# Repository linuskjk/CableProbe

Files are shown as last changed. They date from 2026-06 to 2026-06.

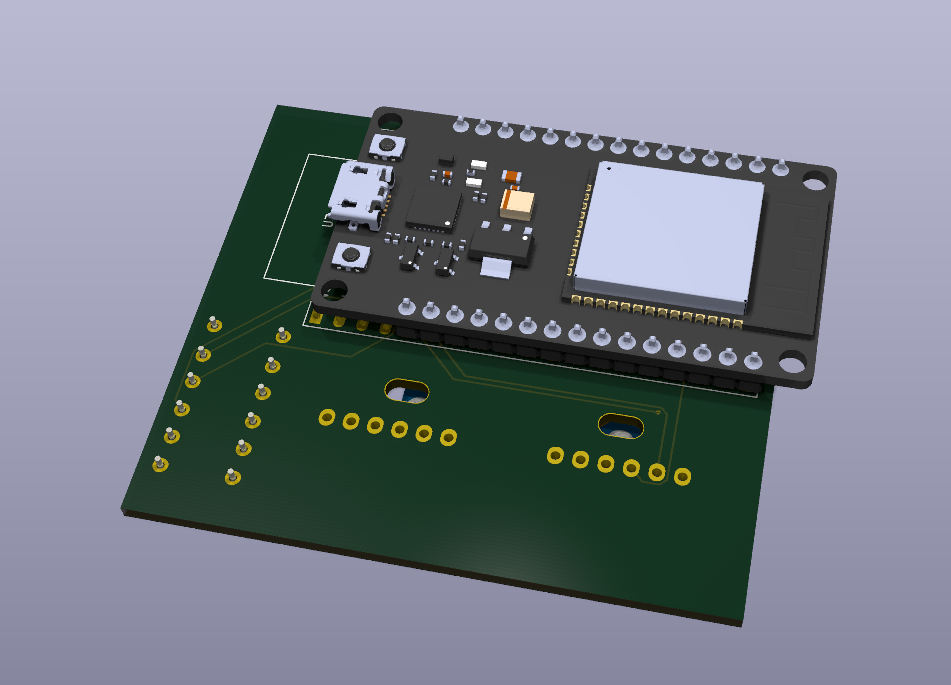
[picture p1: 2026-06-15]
images/pcb_bottom.png

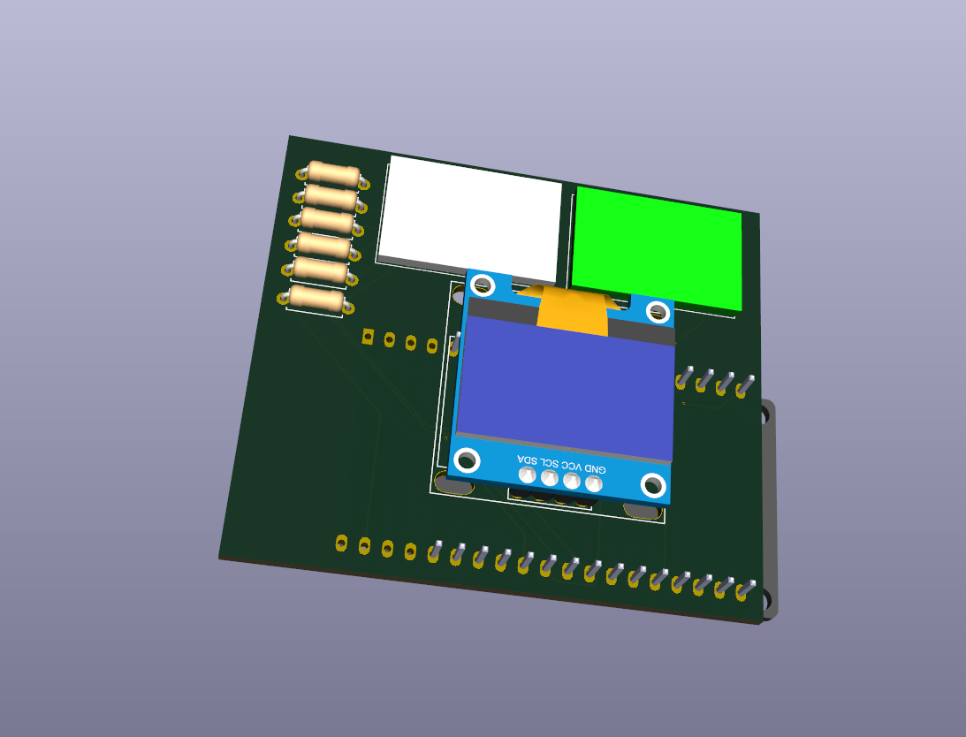
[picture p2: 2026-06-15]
images/pcb_top.png

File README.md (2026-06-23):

zine_page

# CableProbe

A custom ESP32-based tool to analyze and verify USB-C cables.

## TO THE REVIEWER PLEASE READ THE MESSAGE AT THE BOTTOM ;)
## Features

### Analysis
- Basic connectivity check
- Problem detection
- Power throughput & quality
- Fast Charging / Power Delivery support
- General-purpose suitability testing

## Hardware

- ESP32 on a custom PCB
- 2x USB-C modules linked to GPIOs
- 128x64 SSD1306 OLED display
- Basic resistor setup for pin pulling

## Why?

Ever bought a pile of cheap USB-C cables from AliExpress only to find out they are bad? Or struggled to figure out which cable actually supports fast charging?

CableProbe was made to quickly sort through the cable drawer. It identifies the quality and features of almost any USB-C cable without needing a PC or complicated setup.

## Usage

Simply plug both ends of your cable into the USB-C modules and follow the instructions on the screen.

The ESP32 will run through the pins and display the results on the screen. It immediately tells you whether the cable is suitable for:
- charging only,
- fast charging,
- or high-speed applications.

## Images

### Case



### PCB



### ROUTING
routing

### SCHEMATIC



### CASE
## IMPORTANT: THIS IS NOT THE NEWEST VERSION OF THE CASE BUT IT USES THE EXACT SAME FRICTION FIT SO IT ALSO WORKS ON THE NEW VERSION.

https://github.com/user-attachments/assets/e5118ca8-60bc-48c1-94f0-9f646d53b27a

### PROOF THAT MY FRICTION FIT WORKS

https://github.com/user-attachments/assets/f6ddad3f-a20b-4f4a-b254-9df56e5059d4

# Build Your Own

## PCB and Parts

| Reference | Qty | Value | Description | Price EUR | Pack Info | Link |
| --- | --: | --- | --- | ---: | --- | --- |
| Brd1 | 1 | 128x64 OLED | SSD1306 | 2.89 | 1 pc | [Buy](https://de.aliexpress.com/item/1005006514489341.html) |
| R1 R2 R3 R4 R5 R6 | 6 | 1k Ohm | R_Axial_DIN0207_L6.3mm_D2.5mm_P7.62mm_Horizontal | 3.30 | 20 pcs | [Buy](https://amzn.eu/d/0aSOhZVj) |
| U1 U2 | 2 | USB-C Module  | USB-C connector module to connect the cable to | 1.61 | 5 pcs | [Buy](https://de.aliexpress.com/item/1005007314733520.html) |
| U3 | 1 | ESP32-DevKitC | ESP32 development board | 2.99 | 1 pc | [Buy](https://de.aliexpress.com/item/1005006140555903.html) |
| Battery | 1 | 654060 Li-Po 200mAh | Lithium polymer battery | 9.90 | 1 pc | [Buy](https://de.aliexpress.com/item/1005005970679252.html) |
| Charger Module | 1 | TP4057 | USB-C charging module | 3.83 | 1 pc | [Buy](https://de.aliexpress.com/item/1005010764961491.html) |

The PCB is a simple custom design made to hold the ESP32, USB-C modules, and OLED display in a compact enclosure.

## Soldering 

Recommended order:
1. Resistors
2. ESP32
3. USB-C modules
4. OLED display

No special equipment needed.

## Case

3D print the provided STL files.

Both PLA and PETG work perfectly fine. I recommend using PLA. 
I have already printed and tested the case. The friction fit works perfectly, and the battery mount fits exactly as intended. The PCB and firmware have also been tested and are working correctly.

## Programming 

**Install the following libraries** (you can find them under firmware/libraries or the library manager:
- *Adafruit_GFX.h*
- *Adafruit_SSD1306.h*

**Flashing** is straightforward:
1. Open 'main.ino' from the 'firmware' folder in your preferred IDE.
2. Select the correct ESP32 board (ESP32 DevKit).
3. Hit upload

## Assembly 

1. Drop the PCB into the bottom half of the case
2. Connect the battery to the charger module (B+/- to the battery terminals and the module output to V+/GND). The charger module is intentionally not mounted on the PCB to save space and allow more flexible battery placement. Simply press the module into the slot at the bottom of the case. It fits securely and withstands considerable force.
3. Align the USB-C ports with the openings
4. Fit the OLED display into place
5. Close the enclosure

To the reviewer: I cant resubmit this anymore so if you reject it I have some serious problems. I already booked my flights and bought a laptop just for the event. I am going homeless if I cant go. But IF there is a problem with my project, can you just not reject it but tell me what to do and after it is done you can approve it. PLEASE. and also if you are wondering about the 3D models of the USB-C modules on the PCB, I unfortunately couldn't find any suitable 3D models for them and was advised to leave them as they are.

Everything is designed to fit snugly without additional hardware.

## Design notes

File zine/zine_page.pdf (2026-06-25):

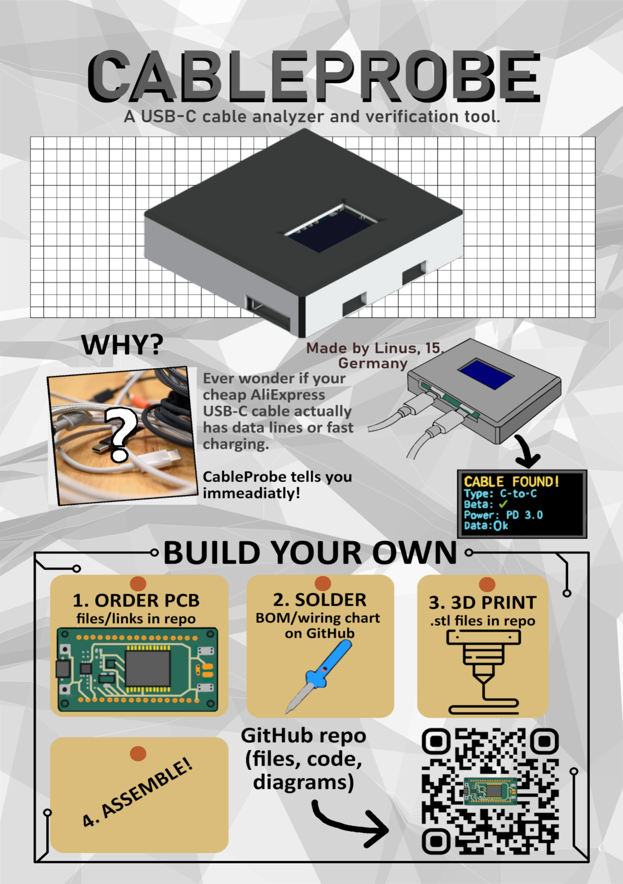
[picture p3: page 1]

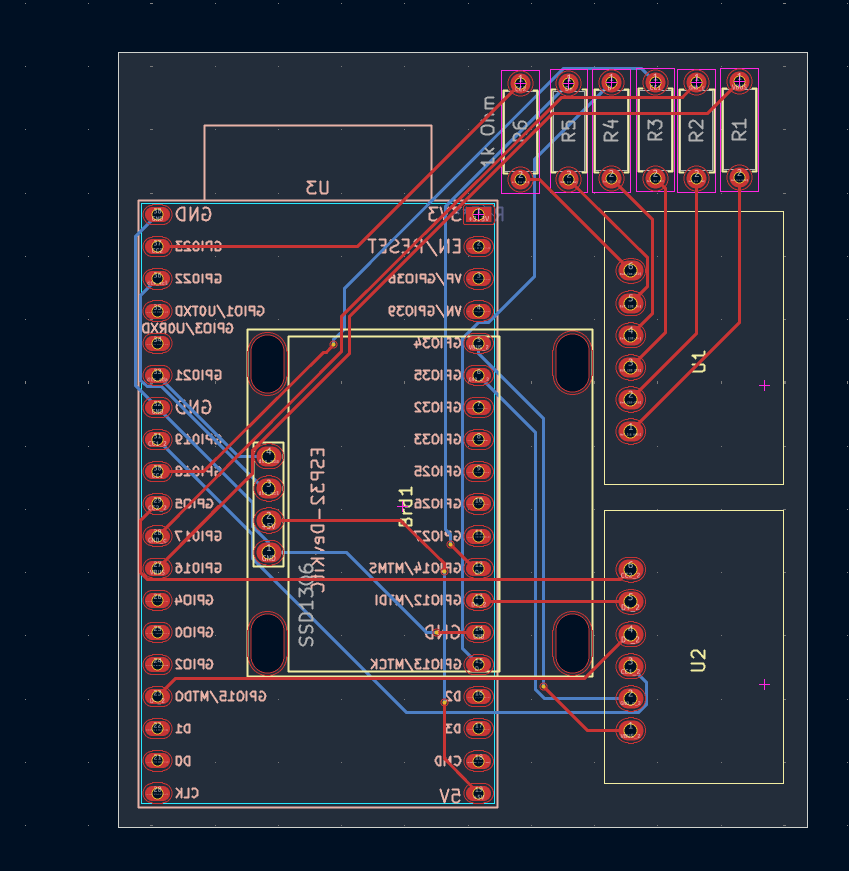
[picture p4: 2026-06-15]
images/routing.png

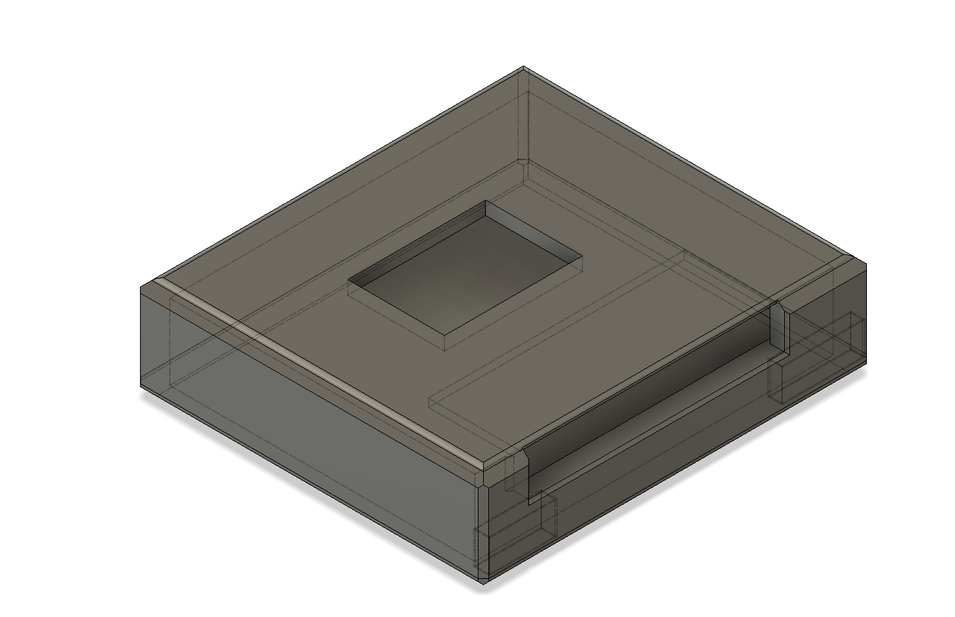
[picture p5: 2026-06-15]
images/case.png

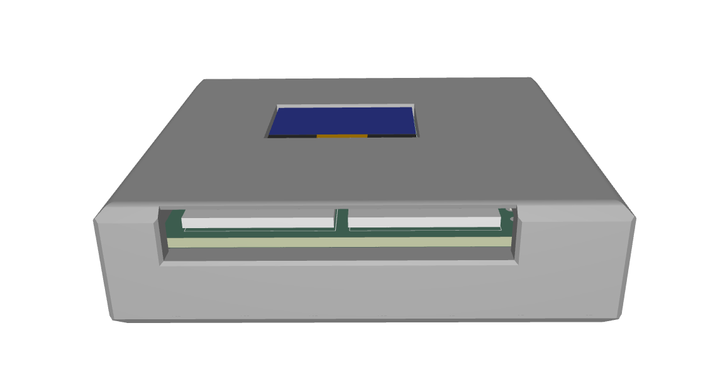
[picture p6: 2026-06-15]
images/case2.png

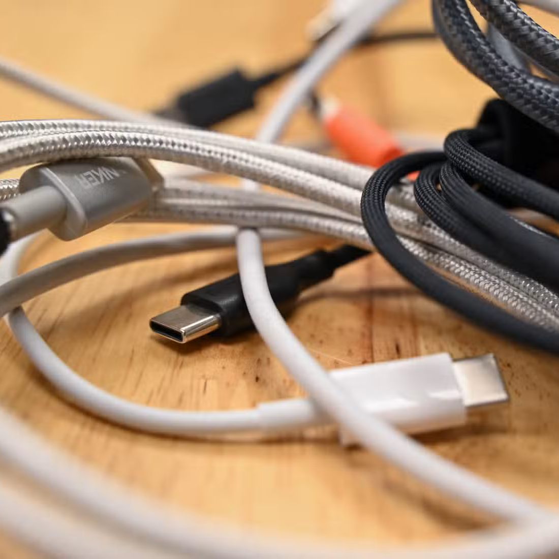
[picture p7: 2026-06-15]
zine/cables.png

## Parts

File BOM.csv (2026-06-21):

Reference | Qty | Value | Description | Price EUR | Pack Info | Link
Brd1 | 1 | 128x64OLED | SSD1306 | 2.89 | 1 pcs | https://de.aliexpress.com/item/1005006514489341.html
R1, R2, R3, R4, R5, R6 | 6 | 1k Ohm | R_Axial_DIN0207_L6.3mm_D2.5mm_P7.62mm_Horizontal | 3.30 | 20 pcs | https://amzn.eu/d/0aSOhZVj
U1, U2 | 2 | usbc_module | usb-c connector module to connect the cable to | 1.61 | 5 | https://de.aliexpress.com/item/1005007314733520.html
U3 | 1 | ESP32-DevKitC | ESP32 development board | 2.99 | 1 pc | https://de.aliexpress.com/item/1005006140555903.html
BAT1 | 1 | 654060 Li-Po 200mAh | Lithium polymer battery | 9.90 | 1 pc | https://de.aliexpress.com/item/1005005970679252.html
U4 | 1 | TP4057 | USB-C charging module | 3.83 | 1 pc | https://de.aliexpress.com/item/1005010764961491.html
TOTAL |  |  | Total price | 24.52 / 21.24

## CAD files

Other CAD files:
case/fully_assembled.step
pcb/pcb_model_not_assembled.step
pcb/pcb_model_assembled.step
case/case.step
case/case.3mf
case/case.f3z
case/case.obj
case/case.stl
case/fully_assembled.3mf
case/fully_assembled.f3z
case/fully_assembled.obj
case/fully_assembled.stl
pcb/pcb_model_assembled.stl
pcb/pcb_model_not_assembled.stl

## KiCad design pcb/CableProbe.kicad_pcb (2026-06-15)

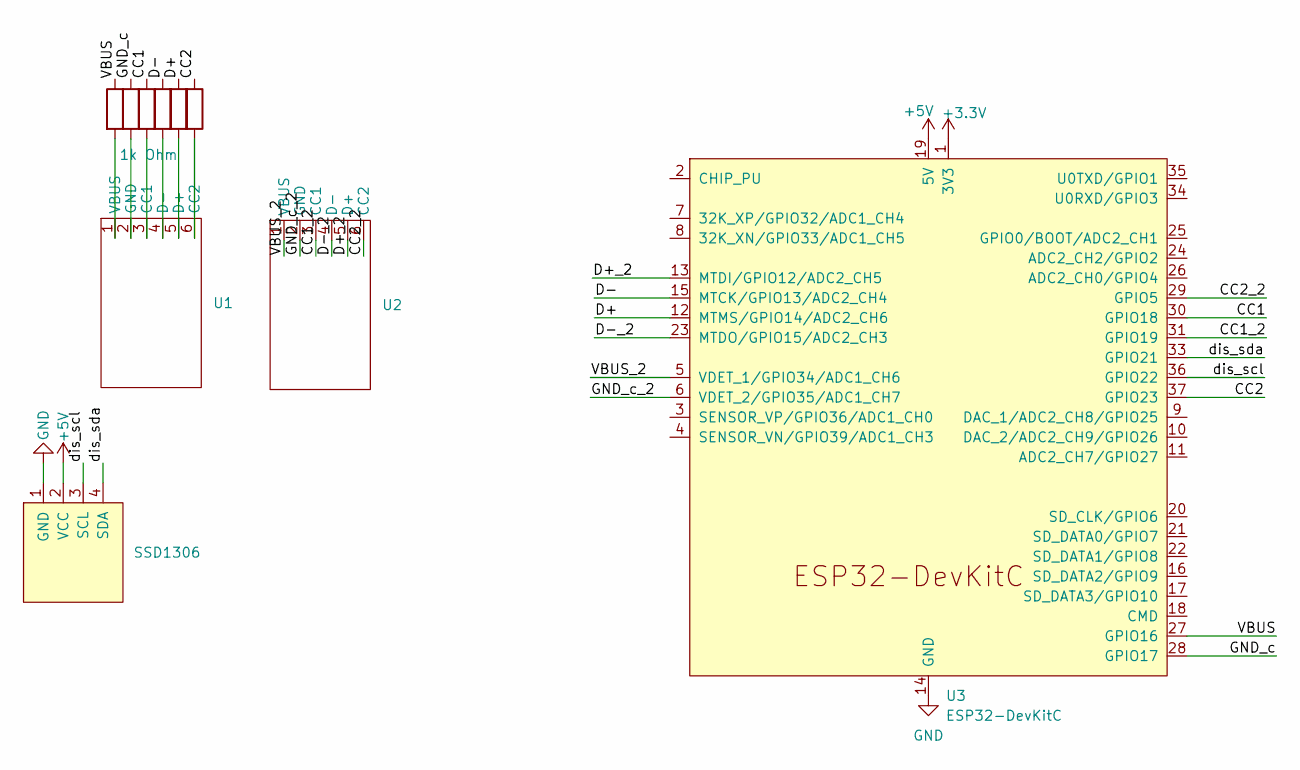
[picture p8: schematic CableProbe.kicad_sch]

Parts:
Brd1: SSD1306; 128x64OLED
R1, R2, R3, R4, R5, R6: 1k Ohm; R_Axial_DIN0207_L6.3mm_D2.5mm_P7.62mm_Horizontal
U1, U2: usbc_bb
U3: ESP32-DevKitC

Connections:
+3.3V: U3.1 (3V3)
+5V: Brd1.2 (VCC), U3.19 (5V)
/CC1: R3.1, U3.30 (GPIO18)
/CC1_2: U2.3 (CC1), U3.31 (GPIO19)
/CC2: R6.1, U3.37 (GPIO23)
/CC2_2: U2.6 (CC2), U3.29 (GPIO5)
/D+: R5.1, U3.12 (MTMS/GPIO14/ADC2_CH6)
/D+_2: U2.5 (D+), U3.13 (MTDI/GPIO12/ADC2_CH5)
/D-: R4.1, U3.15 (MTCK/GPIO13/ADC2_CH4)
/D-_2: U2.4 (D-), U3.23 (MTDO/GPIO15/ADC2_CH3)
/GND_c: R2.1, U3.28 (GPIO17)
/GND_c_2: U2.2 (GND), U3.6 (VDET_2/GPIO35/ADC1_CH7)
/VBUS: R1.1, U3.27 (GPIO16)
/VBUS_2: U2.1 (VBUS), U3.5 (VDET_1/GPIO34/ADC1_CH6)
/dis_scl: Brd1.3 (SCL), U3.36 (GPIO22)
/dis_sda: Brd1.4 (SDA), U3.33 (GPIO21)
GND: Brd1.1 (GND), U3.14 (GND), U3.32 (GND), U3.38 (GND)
unnamed: R3.2, U1.3 (CC1)
unnamed: R6.2, U1.6 (CC2)
unnamed: R5.2, U1.5 (D+)
unnamed: R4.2, U1.4 (D-)
unnamed: R2.2, U1.2 (GND)
unnamed: R1.2, U1.1 (VBUS)

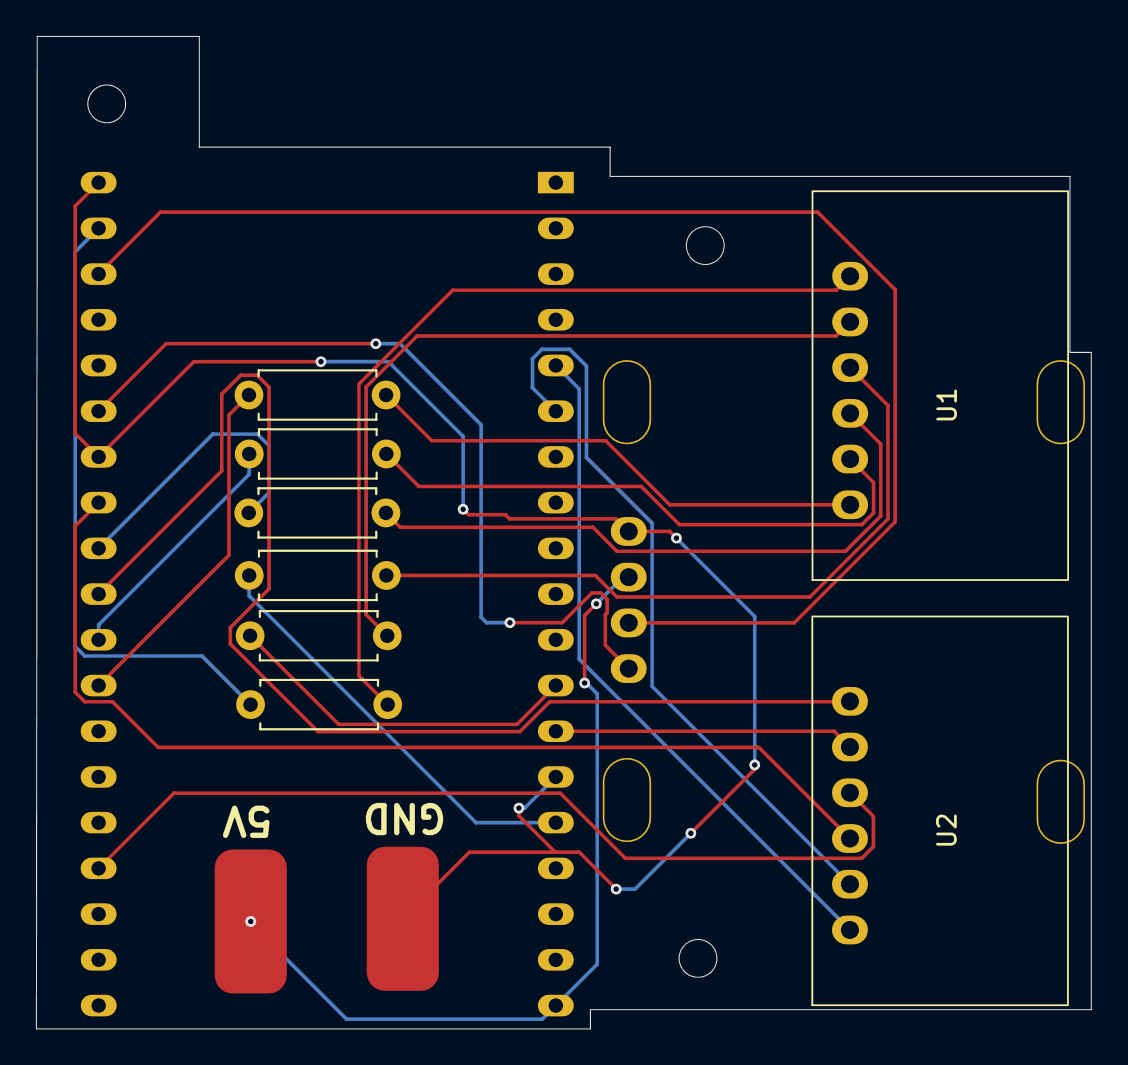
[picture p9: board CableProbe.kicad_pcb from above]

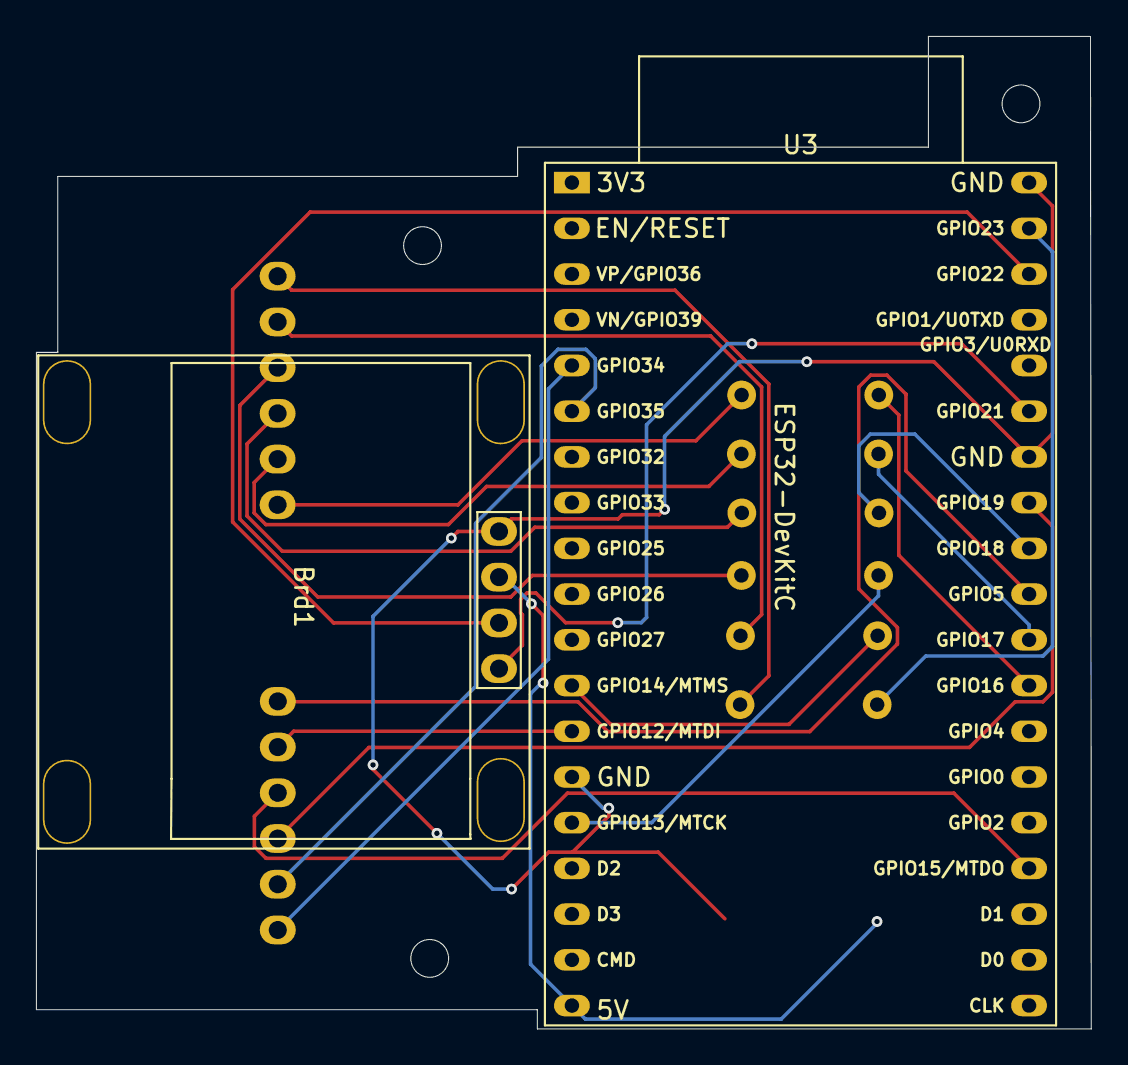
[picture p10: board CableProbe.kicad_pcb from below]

Board: 2 copper layers, 58.6 x 55.1 mm, 13 parts (2 on the bottom side), 22 nets.

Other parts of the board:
M1, M2, M3: MountingHole_2.1mm

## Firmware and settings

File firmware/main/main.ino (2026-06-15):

#include <SPI.h>
#include <Wire.h>
#include <Adafruit_GFX.h>
#include <Adafruit_SSD1306.h>

#define SCREEN_WIDTH 128
#define SCREEN_HEIGHT 64

#define OLED_RESET    -1 
Adafruit_SSD1306 display(SCREEN_WIDTH, SCREEN_HEIGHT, &Wire, OLED_RESET);



#define VBUS_OUT    13
#define GND_OUT     12
#define CC1_OUT     14
#define D_minus_OUT 27
#define D_plus_OUT  26
#define CC2_OUT     25

#define VBUS_IN     33
#define GND_IN      32
#define CC1_IN      19
#define D_minus_IN  18
#define D_plus_IN   4   
#define CC2_IN      5   


static const unsigned char PROGMEM logo_bmp[] = { 
	0x00, 0x00, 0x00, 0x00, 0x00, 0x00, 0x00, 0x00, 0x00, 0x00, 0x00, 0x00, 0x00, 0x00, 0x00, 0x00, 
	0x00, 0x00, 0x00, 0x00, 0x00, 0x00, 0x00, 0x00, 0x00, 0x00, 0x00, 0x00, 0x00, 0x00, 0x00, 0x00, 
	0x00, 0x00, 0x00, 0x00, 0x00, 0x00, 0x00, 0x00, 0x00, 0x00, 0x00, 0x00, 0x00, 0x00, 0x00, 0x00, 
	0x00, 0x00, 0x00, 0x00, 0x00, 0x00, 0x00, 0x00, 0x00, 0x00, 0x00, 0x00, 0x00, 0x00, 0x00, 0x00, 
	0x00, 0x00, 0x00, 0x00, 0x00, 0x00, 0x00, 0x00, 0x00, 0x00, 0x00, 0x00, 0x00, 0x00, 0x00, 0x00, 
	0x00, 0x00, 0x00, 0x00, 0x00, 0x00, 0x00, 0x00, 0x00, 0x00, 0x00, 0x00, 0x00, 0x00, 0x00, 0x00, 
	0x00, 0x00, 0x00, 0x00, 0x00, 0x00, 0x00, 0x00, 0x00, 0x00, 0x00, 0x00, 0x00, 0x00, 0x00, 0x00, 
	0x00, 0x00, 0x00, 0x00, 0x00, 0x00, 0x00, 0x00, 0x00, 0x00, 0x00, 0x00, 0x00, 0x00, 0x00, 0x00, 
	0x00, 0x00, 0x00, 0x00, 0x00, 0x00, 0x00, 0x00, 0x00, 0x00, 0x00, 0x00, 0x00, 0x00, 0x00, 0x00, 
	0x00, 0x00, 0x00, 0x00, 0x00, 0x00, 0x00, 0x00, 0x00, 0x00, 0x00, 0x00, 0x00, 0x00, 0x00, 0x00, 
	0x00, 0x00, 0x7f, 0xff, 0xff, 0xfe, 0x00, 0x00, 0x00, 0x03, 0xff, 0xff, 0xff, 0xff, 0xc0, 0x00, 
	0x00, 0x07, 0xff, 0xff, 0xff, 0xff, 0xe0, 0x00, 0x00, 0x0f, 0xff, 0xff, 0xff, 0xff, 0xf8, 0x00, 
	0x00, 0x1f, 0x80, 0x00, 0x00, 0x01, 0xf8, 0x00, 0x00, 0x3e, 0x00, 0x00, 0x00, 0x00, 0x7c, 0x00, 0x00, 
	0x00, 0x7c, 0x00, 0x00, 0x00, 0x00, 0x3e, 0x00, 0x00, 0x78, 0x00, 0x00, 0x00, 0x00, 0x1e, 0x00, 
	0x00, 0x78, 0x00, 0x00, 0x00, 0x00, 0x1e, 0x00, 0x00, 0xf0, 0x00, 0x00, 0x00, 0x00, 0x0f, 0x00, 
	0x00, 0xf0, 0x1f, 0xff, 0xff, 0xf8, 0x0f, 0x00, 0x00, 0xf0, 0x3f, 0xff, 0xff, 0xfc, 0x0f, 0x00, 
	0x00, 0xf0, 0x3f, 0xff, 0xff, 0xfc, 0x0f, 0x00, 0x00, 0xf0, 0x1f, 0xff, 0xff, 0xf8, 0x0f, 0x00, 
	0x00, 0xf0, 0x00, 0x00, 0x00, 0x00, 0x0f, 0x00, 0x00, 0x78, 0x00, 0x00, 0x00, 0x00, 0x1e, 0x00, 
	0x00, 0x78, 0x00, 0x00, 0x00, 0x00, 0x1e, 0x00, 0x00, 0x7c, 0x00, 0x00, 0x00, 0x00, 0x3e, 0x00, 
	0x00, 0x3e, 0x00, 0x00, 0x00, 0x00, 0x7c, 0x00, 0x00, 0x1f, 0x80, 0x00, 0x00, 0x01, 0xf8, 0x00, 
	0x00, 0x0f, 0xff, 0xff, 0xff, 0xff, 0xf8, 0x00, 0x00, 0x07, 0xff, 0xff, 0xff, 0xff, 0xe0, 0x00, 
	0x00, 0x03, 0xff, 0xff, 0xff, 0xff, 0xc0, 0x00, 0x00, 0x00, 0x7f, 0xff, 0xff, 0xfe, 0x00, 0x00, 
	0x00, 0x00, 0x00, 0x00, 0x00, 0x00, 0x00, 0x00, 0x00, 0x00, 0x00, 0x00, 0x00, 0x00, 0x00, 0x00, 
	0x00, 0x00, 0x00, 0x00, 0x00, 0x00, 0x00, 0x00, 0x00, 0x00, 0x00, 0x00, 0x00, 0x00, 0x00, 0x00, 
	0x00, 0x00, 0x00, 0x00, 0x00, 0x00, 0x00, 0x00, 0x00, 0x00, 0x00, 0x00, 0x00, 0x00, 0x00, 0x00, 
	0x00, 0x00, 0x00, 0x00, 0x00, 0x00, 0x00, 0x00, 0x00, 0x00, 0x00, 0x00, 0x00, 0x00, 0x00, 0x00, 
	0x00, 0x00, 0x00, 0x00, 0x00, 0x00, 0x00, 0x00, 0x00, 0x00, 0x00, 0x00, 0x00, 0x00, 0x00, 0x00, 
	0x00, 0x00, 0x00, 0x00, 0x00, 0x00, 0x00, 0x00, 0x00, 0x00, 0x00, 0x00, 0x00, 0x00, 0x00, 0x00, 
	0x00, 0x00, 0x00, 0x00, 0x00, 0x00, 0x00, 0x00, 0x00, 0x00, 0x00, 0x00, 0x00, 0x00, 0x00, 0x00, 
	0x00, 0x00, 0x00, 0x00, 0x00, 0x00, 0x00, 0x00, 0x00, 0x00, 0x00, 0x00, 0x00, 0x00, 0x00, 0x00, 
	0x00, 0x00, 0x00, 0x00, 0x00, 0x00, 0x00, 0x00, 0x00, 0x00, 0x00, 0x00, 0x00, 0x00, 0x00, 0x00, 
	0x00, 0x00, 0x00, 0x00, 0x00, 0x00, 0x00, 0x00, 0x00, 0x00, 0x00, 0x00, 0x00, 0x00, 0x00, 0x00
};

uint8_t outs[] = {
  VBUS_OUT, 
  GND_OUT, 
  CC1_OUT, 
  D_minus_OUT, 
  D_plus_OUT, 
  CC2_OUT};
uint8_t ins[]  = {
  VBUS_IN, 
  GND_IN, 
  CC1_IN, 
  D_minus_IN, 
  D_plus_IN, 
  CC2_IN};
String pinNames[] = {
  "VBUS", 
  "GND", 
  "CC1", 
  "D_MINUS", 
  "D_PLUS", 
  "CC2"};

uint32_t successCounts[] = {0, 0, 0, 0, 0, 0};
bool latchFaults[] = {false, false, false, false, false, false};
uint32_t totalSamples = 0;
unsigned long lastDisconnectTime = 0;
int twistStep = 0;
bool sideA[6], sideB[6];
unsigned long promptTime = 0;

String test(int mode);
bool isCableConnected();
void goToSleep();
void updateDisplay(int mode, String json);


void showSplash() {
  for (int i = 0; i <= 100; i += 2) {
    display.clearDisplay(); 
    display.drawBitmap(32, 0, logo_bmp, 64, 64, SSD1306_WHITE);
    display.drawRect(24, 48, 80, 8, WHITE);
    int barWidth = map(i, 0, 100, 0, 76);
    display.fillRect(26, 50, barWidth, 4, WHITE);
    display.setTextSize(1);
    display.setCursor(108, 48);
    display.display();
    delay(15);
  }
  delay(300);
}

void setup() {
  Wire.begin(21, 22); 
  Serial.begin(115200);
  
  if(!display.begin(SSD1306_SWITCHCAPVCC, 0x3C)) {
    Serial.println(F("SSD1306 failed"));
  }
  display.clearDisplay();
  display.setTextColor(WHITE);
  display.setTextSize(1);

  for (uint8_t pin : outs) pinMode(pin, OUTPUT);
  for (uint8_t pin : ins)  pinMode(pin, INPUT_PULLDOWN);

  delay(200);

  showSplash();
  Serial.println("CableProbe Multi-Mode Wakeup.");

  if (!isCableConnected()) {
    goToSleep();
  }
}

void loop() {
  int sequence[] = {9, 3, 4, 6, 7, 8}; 
  
  for (int m : sequence) {
    unsigned long modeStartTime = millis();
    
    // Zeige jeden Modus für 10 Sekunden
    while (millis() - modeStartTime < 10000) {
      if (!isCableConnected()) goToSleep();
      
      String result = test(m);
      updateDisplay(m, result);
      delay(100); 
    }
  }
  
}

bool isCableConnected() {
  digitalWrite(VBUS_OUT, HIGH);
  delay(5);
  bool connected = (digitalRead(VBUS_IN) == HIGH);
  digitalWrite(VBUS_OUT, LOW);
  return connected;
}

void goToSleep() {
  display.clearDisplay();
  display.setCursor(20, 25);
  display.setTextSize(2);
  display.println("NO CABLE");
  display.setTextSize(1);
  display.setCursor(25, 45);
  display.println("Sleeping...");
  display.display();
  delay(3000);
  
  display.ssd1306_command(SSD1306_DISPLAYOFF);
  
  esp_sleep_enable_ext0_wakeup((gpio_num_t)VBUS_IN, 1); 
  esp_deep_sleep_start();
}



void updateDisplay(int mode, String json) {

  digitalWrite(VBUS_OUT, HIGH);
  delayMicroseconds(50);
  bool shortToGnd = (digitalRead(GND_IN) == HIGH);
  digitalWrite(VBUS_OUT, LOW);

  if(shortToGnd) {
    display.clearDisplay();
    display.setTextSize(2);
    display.setCursor(10, 10);
    display.println("!!! DANGER !!!");
    display.setTextSize(1);
    display.setCursor(10, 35);
    display.println("SHORT CIRCUIT:");
    display.setCursor(10, 45);
    display.println("VBUS <-> GND");
    display.display();
    return;
  }


  display.clearDisplay();
  display.setTextSize(1);
  
  display.setCursor(0, 0);
  display.print("MODE "); display.print(mode);
  if ((millis() / 500) % 2) display.fillRect(120, 0, 3, 3, WHITE);
  display.drawLine(0, 9, 128, 9, WHITE);

  if (mode == 9 || mode == 3) {
    display.setTextSize(2);
    display.setCursor(0, 20);
    if (json.indexOf("PD_FULL") > 0 || json.indexOf("fast_charge:OK") > 0) display.println("SUPER VOOC");
    else if (json.indexOf("USB2") > 0) display.println("USB 2.0");
    else if (json.indexOf("POWER") > 0) display.println("CHARGE ONLY");
    else display.println("NO CABLE");
    display.setTextSize(1);
    display.setCursor(0, 50);
    display.print(json.indexOf("DATA:OK") > 0 ? "[DATA] " : "");
    display.print(json.indexOf("PWR:OK") > 0 ? "[PWR]" : "");
  }

  else if (mode == 4 || mode == 7) {
    for (int i = 0; i < 6; i++) {
      int y = 14 + (i * 8);
      display.setCursor(0, y);
      display.print(pinNames[i]);
      
      if (mode == 4) {
        int barWidth = map(successCounts[i] * 100 / (totalSamples > 0 ? totalSamples : 1), 0, 100, 0, 80);
        display.drawRect(45, y, 80, 5, WHITE);
        display.fillRect(45, y, barWidth, 5, WHITE);
      } else {
        display.setCursor(50, y);
        display.print(latchFaults[i] ? "!!! FAILED !!!" : "LOCKED OK");
      }
    }
  }

  else if (mode == 1 || mode == 2) {
    for (int i = 0; i < 6; i++) {
      int yLeft = 14 + (i * 8);
      display.setCursor(0, yLeft);
      display.print(pinNames[i]);
      
      digitalWrite(outs[i], HIGH);
      delayMicroseconds(50);
      bool connected = (digitalRead(ins[i]) == HIGH);
      digitalWrite(outs[i], LOW);

      if (connected) {
        display.drawLine(40, yLeft + 3, 110, yLeft + 3, WHITE);
        display.fillCircle(115, yLeft + 3, 2, WHITE);           
      } else {
        display.setCursor(110, yLeft);
        display.print("X"); 
      }
    }
  }

  else if (mode == 6) {
    for (int i = 0; i < 6; i++) {
      int y = 14 + (i * 8);
      int raw = analogRead(ins[i]);
      int graphVal = map(raw, 0, 4095, 0, 80);
      display.setCursor(0, y);
      display.print(pinNames[i][0]);
      display.fillRect(15, y + 2, graphVal, 3, WHITE);
      display.setCursor(100, y);
      display.print(raw / 1000.0, 1); display.print("V");
    }
  }

  else if (mode == 8) {
    display.setTextSize(2);
    display.setCursor(10, 25);
    if (json.indexOf("CLEAN") > 0) {
      display.println("SHIELD: OK");
      display.drawCircle(64, 45, 10, WHITE);
    } else {
      display.println("NOISE!!");
      display.fillTriangle(64, 40, 54, 60, 74, 60, WHITE);
    }
  }

  else if (mode == 5) {
    display.setTextSize(1);
    if (twistStep == 0) {
      display.setCursor(20, 20); 
      display.println("STEP 1:");
      display.setTextSize(2); 
      display.setCursor(20, 35); 
      display.println("PLUG IN");
    } 
    else if (twistStep == 1) {
      display.setTextSize(2); 
      display.setCursor(15, 30); 
      display.println("UNPLUG!");
      display.drawRect(10, 25, 108, 25, WHITE);
    } 
    else if (twistStep == 2) {
      display.setCursor(20, 20); 
      display.println("STEP 2:");
      display.setTextSize(2); 
      display.setCursor(20, 35); 
      display.println("FLIP & IN");
    } 
    else if (twistStep == 3) {
      bool sym = (json.indexOf("SYMMETRIC") > 0);
      display.setCursor(0, 15); 
      display.setTextSize(2);
      display.println(sym ? "PERFECT" : "BAD TWIST");
      display.setTextSize(1);
      display.setCursor(0, 40);
      display.println(sym ? "Symmetric connection" : "Check CC/Data pins!");
    }
  }


  display.display();
}


String test(int mode) {
  String output = "{";
  size_t count = 6;
  bool anyConnection = false;
  bool hasData = false, hasCC = false, hasVBUS = false;

  for (int i = 0; i < count; i++) {
    digitalWrite(outs[i], HIGH); delayMicroseconds(50);
    if (digitalRead(ins[i]) == HIGH) anyConnection = true;
    digitalWrite(outs[i], LOW);
  }


  for (int i = 0; i < count; i++) {
    for (int k = 0; k < count; k++) { pinMode(ins[k], OUTPUT); digitalWrite(ins[k], LOW); }
    delay(2);
    for (int k = 0; k < count; k++) { pinMode(ins[k], INPUT_PULLDOWN); }

    digitalWrite(outs[i], HIGH); delay(10);
    bool selfConnected = (digitalRead(ins[i]) == HIGH);

    if (selfConnected) {
      if (pinNames[i] == "VBUS") hasVBUS = true;
      if (pinNames[i] == "CC1" || pinNames[i] == "CC2") hasCC = true;
      if (pinNames[i] == "D_MINUS" || pinNames[i] == "D_PLUS") hasData = true;
    }

    if (mode == 1 || mode == 2) {
      output += "\"" + pinNames[i] + "\": ";
      if (mode == 1) output += (selfConnected ? "true" : "false");
      else {
        output += "[";
        bool first = true;
        for (int j = 0; j < count; j++) {
          if (digitalRead(ins[j]) == HIGH) {
            if (!first) output += ",";
            output += pinNames[j];
            first = false;
          }
        }
        output += "]";
      }
      if (i < count - 1) output += ", ";
    }

    if (mode == 4 && anyConnection) {
      if (selfConnected) successCounts[i]++;
      if (i == count - 1) totalSamples++;
    }

    if (mode == 7 && anyConnection) {
      if (!selfConnected) latchFaults[i] = true;
    }
    digitalWrite(outs[i], LOW);
  }

  if (mode == 3) {
    output += "PWR:" + String(hasVBUS?"OK":"NO") + ", CC:" + String(hasCC?"OK":"NO") + ", DATA:" + String(hasData?"OK":"NO");
  }
  if (mode == 4) {
    for (int i = 0; i < count; i++) {
      float pct = (totalSamples > 0) ? (successCounts[i] * 100.0 / totalSamples) : 0;
      output += pinNames[i] + ":" + String(pct, 0) + "% ";
    }
  }


  if (mode == 5) { 
    if (twistStep == 0 && anyConnection) { 
      for(int i=0; i<6; i++) { 
        digitalWrite(outs[i], HIGH); 
        delay(5); 
        sideA[i] = (digitalRead(ins[i]) == HIGH); 
        digitalWrite(outs[i], LOW); 
        } 
        twistStep=1; 
      }
    else if (twistStep == 1 && !anyConnection) twistStep = 2;
    else if (twistStep == 2 && anyConnection) { 
      for(int i=0; i<6; i++) { 
        digitalWrite(outs[i], HIGH); 
        delay(5); 
        sideB[i] = (digitalRead(ins[i]) == HIGH); 
        digitalWrite(outs[i], LOW); 
          } 
        twistStep=3; 
        promptTime = millis(); 
        }
    else if (twistStep == 3) { 
      bool sym = true; 
      for(int i=0; i<6; i++) if(sideA[i]!=sideB[i]) sym=false;
      output += "\"final\": \"" + String(sym ? "SYMMETRIC" : "ASYMMETRIC") + "\"";
      if(millis() - promptTime > 5000) twistStep=0;
    }
  }

  
  if (mode == 6) {
    for(int i=0; i<count; i++) { 
      digitalWrite(outs[i], HIGH); delay(10); 
      output += pinNames[i] + ":" + String(analogRead(ins[i])); 
      digitalWrite(outs[i], LOW); if(i<count-1) output+=",";
    }
  }
  if (mode == 7) {
    for(int i=0; i<count; i++) { output += pinNames[i] + ":" + (latchFaults[i]?"FAIL":"OK") + " "; }
    if (!anyConnection) for(int i=0; i<6; i++) latchFaults[i] = false;
  }
  if (mode == 8) {
    bool noise = false;
    for(int i=0; i<count; i++) { digitalWrite(outs[i], HIGH); for(int j=0; j<count; j++) if(i!=j && digitalRead(ins[j])==HIGH) noise=true; digitalWrite(outs[i], LOW); }
    output += "Shielding:" + String(noise ? "BAD" : "OK");
  }
  if (mode == 9) {
    if (!anyConnection) output += "ID:NONE";
    else if (hasVBUS && hasCC && hasData) output += "ID:PD_FULL";
    else if (hasVBUS && hasData) output += "ID:USB2_DATA";
    else if (hasVBUS) output += "ID:POWER_ONLY";
    else output += "ID:ERROR";
  }

  output += "}";
  return output;
}
